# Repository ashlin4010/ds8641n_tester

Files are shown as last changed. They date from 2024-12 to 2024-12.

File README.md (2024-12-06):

# DS8641N Tester
A simple tester for DS8641N chips.

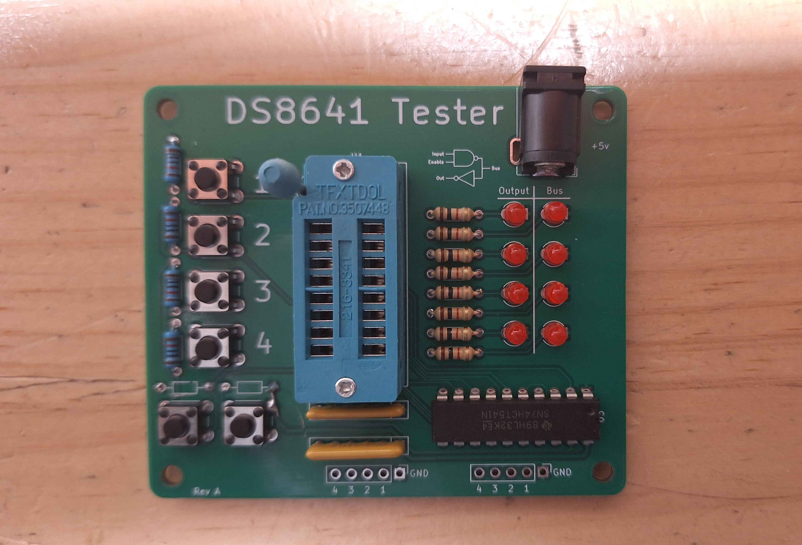
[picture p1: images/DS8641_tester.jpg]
Chip Tester PCB


## Usage ##
 1. Plug it into 5 volt power centre positive power.
 2. Install chip
 3. Press Buttons

## Bill of materials ##

| Quantity | Part | Link |
|:---:|:---:|:---:|
| 8 | 1K Resistor |  |
| 4 | 10K Resistor |  |
| 6 | Push Button | https://www.digikey.co.nz/en/products/detail/same-sky-formerly-cui-devices/TS02-66-70-BK-160-LCR-D/15634243 |
| 1 | Barrel Jack | https://www.digikey.co.nz/en/products/detail/same-sky-formerly-cui-devices/PJ-037A/1644545 |
| 1 | DIP-16 ZIF Socket | https://www.aliexpress.com/item/1005007048855354.html |
| 1 | 74HCT541 | https://www.digikey.co.nz/en/products/detail/texas-instruments/SN74HCT541N/277265 |
| 1 | 390ohm Bussed | https://www.digikey.co.nz/en/products/detail/bourns-inc/4606X-101-391LF/1088986 |
| 1 | 180ohm Bussed | https://www.digikey.co.nz/en/products/detail/bourns-inc/4606X-101-181LF/1088969 |
| 8 | 3mm LED RED |  |

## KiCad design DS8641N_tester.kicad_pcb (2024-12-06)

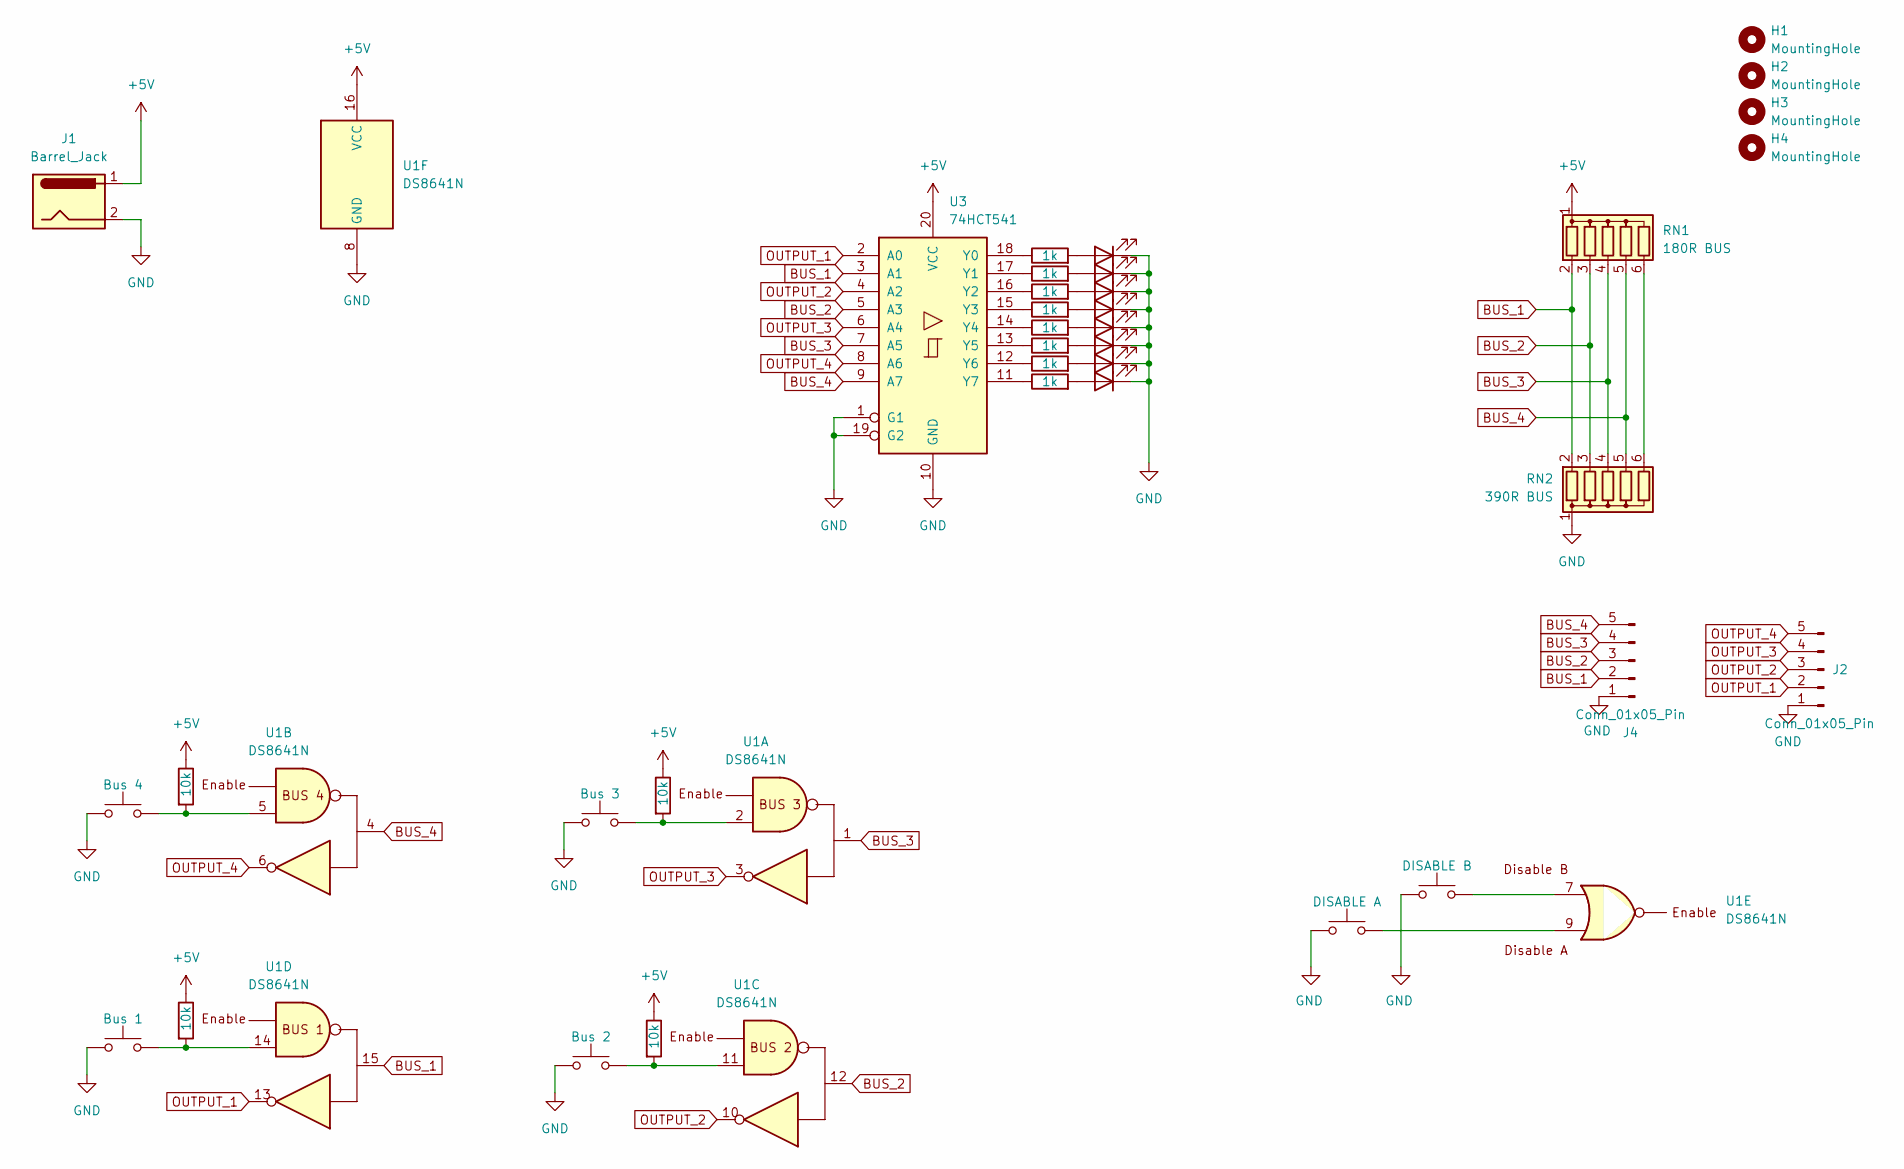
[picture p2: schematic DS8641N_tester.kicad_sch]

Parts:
D2, D3, D4, D5, D6, D7, D8, D9: LED; LED_D3.0mm
H1, H2, H3, H4: MountingHole; MountingHole_3.2mm_M3
J1: Barrel_Jack; BarrelJack_GCT_DCJ200-10-A_Horizontal
J2, J4: Conn_01x05_Pin; PinHeader_1x05_P2.54mm_Vertical
R2, R3, R4, R5: 10k; R_Axial_DIN0204_L3.6mm_D1.6mm_P7.62mm_Horizontal
R8, R9, R10, R11, R12, R13, R14, R15: 1k; R_Axial_DIN0204_L3.6mm_D1.6mm_P7.62mm_Horizontal
RN1: 180R BUS; R_Array_SIP6
RN2: 390R BUS; R_Array_SIP6
SW1: Bus 1; SW_PUSH_6mm_H4.3mm
SW2: Bus 2; SW_PUSH_6mm_H4.3mm
SW3: Bus 3; SW_PUSH_6mm_H4.3mm
SW4: Bus 4; SW_PUSH_6mm_H4.3mm
SW5: DISABLE A; SW_PUSH_6mm_H4.3mm
SW6: DISABLE B; SW_PUSH_6mm_H4.3mm
U1: DS8641N; DIP_Socket-16_W4.3_W5.08_W7.62_W10.16_W10.9_3M_216-3340-00-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
U3: 74HCT541; DIP-20_W7.62mm

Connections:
+5V: J1.1, R2.1, R3.1, R4.1, R5.1, RN1.1 (common), U1.16 (VCC), U3.20 (VCC)
BUS_1: J4.2, RN1.2 (R1), RN2.2 (R1), U1.15, U3.3 (A1)
BUS_2: J4.3, RN1.3 (R2), RN2.3 (R2), U1.12, U3.5 (A3)
BUS_3: J4.4, RN1.4 (R3), RN2.4 (R3), U1.1, U3.7 (A5)
BUS_4: J4.5, RN1.5 (R4), RN2.5 (R4), U1.4, U3.9 (A7)
GND: D2.1 (K), D3.1 (K), D4.1 (K), D5.1 (K), D6.1 (K), D7.1 (K), D8.1 (K), D9.1 (K), J1.2, J2.1, J4.1, RN2.1 (common), SW1.1, SW2.1, SW3.1, SW4.1, SW5.1, SW6.1, U1.8 (GND), U3.1 (G1), U3.10 (GND), U3.19 (G2)
unnamed: D2.2 (A), R8.2
unnamed: D3.2 (A), R9.2
unnamed: D4.2 (A), R10.2
unnamed: D5.2 (A), R11.2
unnamed: D6.2 (A), R12.2
unnamed: D7.2 (A), R13.2
unnamed: D8.2 (A), R14.2
unnamed: D9.2 (A), R15.2
unnamed: R2.2, SW1.2, U1.14
unnamed: R3.2, SW2.2, U1.11
unnamed: R4.2, SW3.2, U1.2
unnamed: R5.2, SW4.2, U1.5
unnamed: RN1.6 (R5), RN2.6 (R5)
unnamed: SW5.2, U1.9
unnamed: SW6.2, U1.7
unnamed: R8.1, U3.18 (Y0)
unnamed: R9.1, U3.17 (Y1)
unnamed: R10.1, U3.16 (Y2)
unnamed: R11.1, U3.15 (Y3)
unnamed: R12.1, U3.14 (Y4)
unnamed: R13.1, U3.13 (Y5)
unnamed: R14.1, U3.12 (Y6)
unnamed: R15.1, U3.11 (Y7)
OUTPUT_1: J2.2, U1.13, U3.2 (A0)
OUTPUT_2: J2.3, U1.10, U3.4 (A2)
OUTPUT_3: J2.4, U1.3, U3.6 (A4)
OUTPUT_4: J2.5, U1.6, U3.8 (A6)

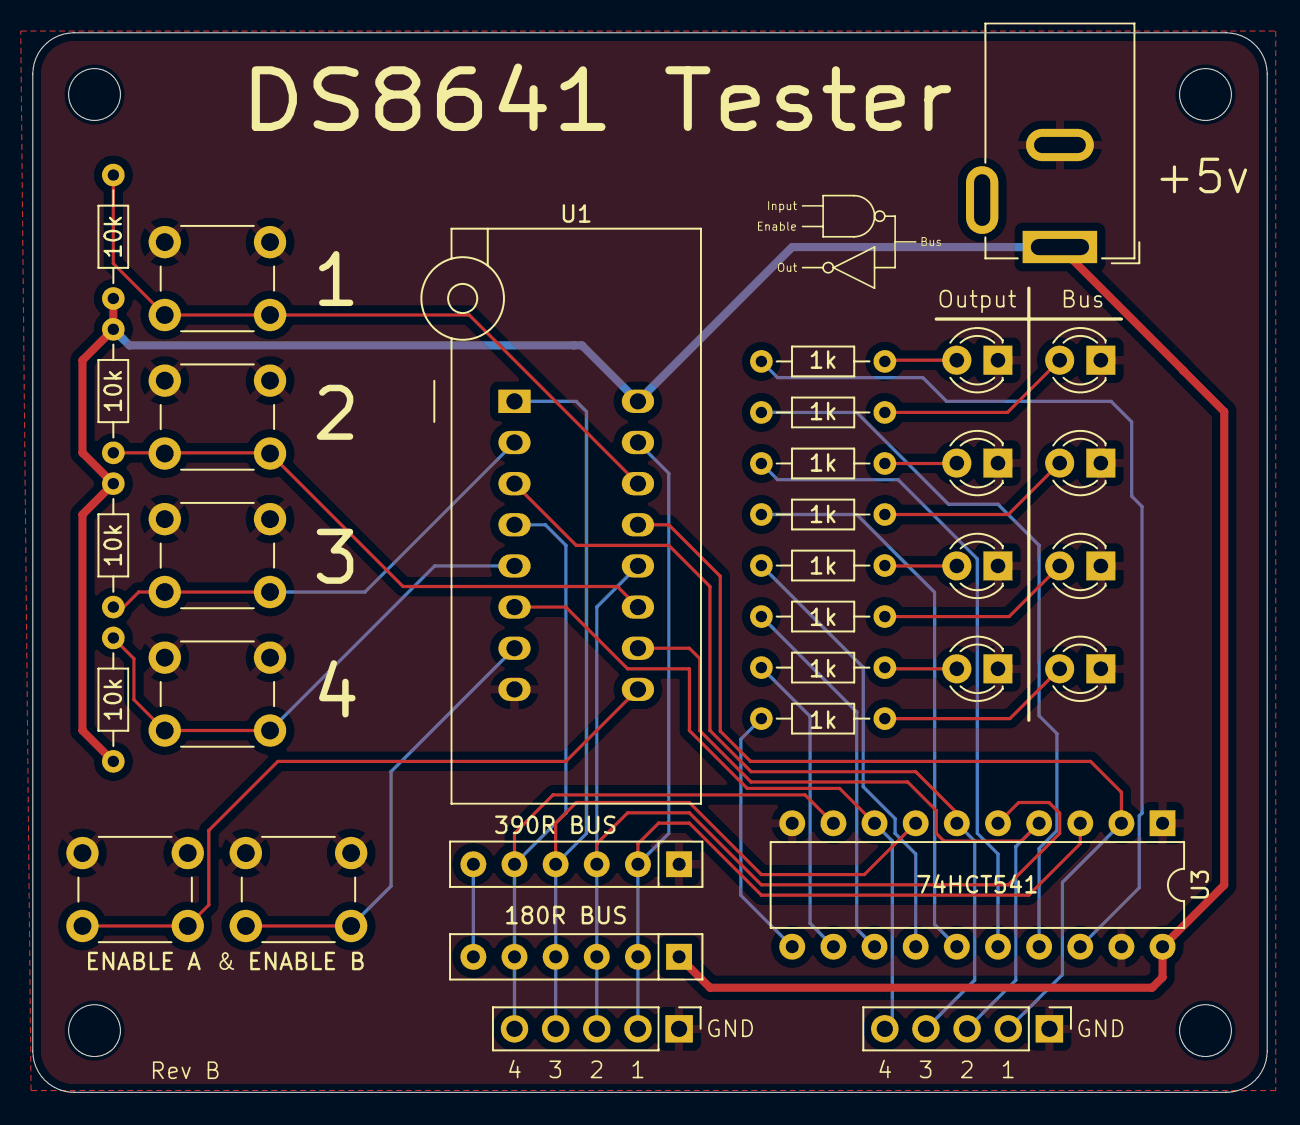
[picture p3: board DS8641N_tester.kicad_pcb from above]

Board: 2 copper layers, 76.2 x 65.4 mm, 37 parts (0 on the bottom side), 33 nets.

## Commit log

2024-11-19 Added PCB files
    [DS8641N_tester-B_Cu.gbl, DS8641N_tester-B_Mask.gbs, DS8641N_tester-B_Silkscreen.gbo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]
2024-12-06 Added image and small fix
    [DS8641N_tester-B_Cu.gbl, DS8641N_tester-B_Mask.gbs, DS8641N_tester-B_Silkscreen.gbo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]
